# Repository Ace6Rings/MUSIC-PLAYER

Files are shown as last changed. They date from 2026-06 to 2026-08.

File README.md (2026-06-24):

# NOIR MUSIC PLAYER
Noir Music Player (3)

# Why?

Why did I build something like this? Well, I am sick and tired of buying spotify premium every month. I looked for mp3 players online but nearly all of them have the same flaw(s). 
They either have a very short battery life or they don't support bluetooth. This would mean that my headphones will last three times as long as a typical mp3 player. So, I solved all of these problems with my own music player.

# Features

  - expandable storage via micro sd card
  - bluetooth range of ~100 meters in open air
  - Dual compatibility with both wired and wireless. 
  - High quality wired and wireless audio
  - Extremely high battery life (not tested)

## Electronics

So what about my electronics makes these features possible?

I use the NRF5430 <br>
  - The NRF5430 is a dual core chip that have the capability of being hyper efficient during its operation. <br>
  - Its power consumption is measured in the microamps during sleep mode and miliamps during full operation.

The PCM5102A and the TPA6132A2RTE <br>
  - the audio from common microcontrollers are low quality and unenjoyable for music. So I used the PCM5102A. It is a high quality DAC which will be wired to the TPA6132ARTE. <br>
  - the TPA6132ARTE increases the volume of the sound and also helps with the bass.<br>
  - with these two components, the wired quality should be no different (if not, better) than a phone or a typical mp3 player.

What about some safety features?

I have 2 layers of protection.

  According to my schematic, the battery and the usbc is tied to the same net. This means that they share the same electrical path.<br>
  To prevent any damage, I used mosfets which prevents both of them from turning on at the same time.<br>
  Additionally, I used the PRTR5V0U2X. It is a tvs diode which can prevent damage to the usbc and the board if something goes horribly wrong.

The rest of the electronics can be found in the electronics subdirectory. You can also find the production files there too. For the reviewer, make sure to read the mini readme in the electronics directory.
step 1 (2)

## Mechanical

The case of the music player is largely modeled after the Iphone 16 pro's dimensions. It is a reasonable size for a mp3 player and is also the reason why I can fit such a big battery.

There isn't any special about the case itself. This is designed for printers like the A1 mini, A1, and X1 Carbon with PLA basic.
If you took a look at my CAD already, you might be worried about how thin the wall is at the micro sd slot. So I ran some simulations.

I put a force of 20 newtons onto the faces of the socket and made the opposite wall a fixed support.
There could be more things you might want to see. You can do that under MECHANICAL and then click on simulations. <br>
NOTE: you need both the workbench file and also the zipped file too
CONTROL
control
This is the "before" part of the simulation.
defform
And this is the after. 

Pretty much the same right? this means that my design is sound and could be used (as long as the user isn't a brute)

## Code
### MAKE SURE TO READ THE CORRESPONDING README INCLUDED IN THE CODE DIRECTORY TO ACTUALLY BUILD IT.
The backend of the code is built entirely by NORDIC, the company behind the NRF chips. I used their existing audio code so that I don't need to code my own (they have tens of thousands of lines of code)

The gui and function is limited because I have not recieved my pcb yet, and won't know what will happen if i implement something more than audio playback and some config files. This will change once I get my pcb.

Also note that the vast majority of the code is by NORDIC and their open source templates. All I did was make config files.

# Process

So what exactly is under the hood? Its a big schematic, so there is going to be 3 images.

## Schematic


As you can see, I'm using the NRF 5340 to power this project. Is there really much to say about this as of right now? Not really.



In this image, we can see that I'm using the TPA and PCM. These components work together to make wired audio great (hopefully). On the user side, you don't have to worry about this.
There is a headphone jack, and that is where you're going to plug in your headphones.



(yeah i don't know what to say about the schematic, I guess its cool?)

## PCB

If you've already opened the PCB file, then you might've been confused or bamboozled by how messy it is. But it really isn't!

This is what it is supposed to look like without user drawings (i used them to align things but never deleted them so I remember how much pain I went through).

Everything that needed to be said is already said in the features subtitle, but as an addendum, I added a cool snowman.



# How to use
Well how do you use it? I don't really know to be honest. The code is rudimentary and will be improved upon when I get my parts. As of right now, the controls are simple. The four buttons indicate direction, the center button indicates selection, and the rotary encoder is for volume up down and also a faster way to navigate the (future) gui.

# How to build

If you want to know how to build this physically, then heres a simple guide.

Thankfully, you don't need to do much at all! (assuming your pcb is already assembled. If not, good luck)

INSTRUCTION DIAGRAM (1)-1

Just follow the steps in order!

1.Grab a soldering iron to put heat set inserts into the hole that label 1 is indicating. This is OPTIONAL, but you will need to adjust the cad to make it 2mm instead of 3mm.<br>
2.Screw in the screws as indicated in Label 1. There is only two holes but four mounts. Make sure to orientate it correctly! (the ports should line up with the case)<br>
3.Put the battery inside the two walls as indicated in label 2. Since everyone's printers are different, you will likely have to sand it. You can put double sided tape or velcro to secure the battery further, but otherwise, it should be fine. <br>
4.Put the ANO encoder into the cutout as indicated in Label 4.<br>
5.Put the cover onto the ANO encoder as indicated in Label 5.<br>
6.Screw it both in as indicated in Label 6.<br>
6.Use the JST compatible wires and connect them to the PCB.<br>
7.Do the same thing you just did to the ANO encoder in step 3. Instead, this time, you'll apply the same principle to the screen in Label 7, 8, and 9.<br>
NOTE: If you are unconfident in your soldering abilities, especially for the screen, you may adjust the "leeway" variable under "screen" folder and then the "mount" subfolder. The default is 2mm, do not go past 2.1mm. You may lower it if you want to, but the default should be ok. In addition, it is not reccomended to use the included pin headers for the screen, just solder the wire directly. The cover will hide any cosmetic issues.<br>

Hey! What about the battery? <br>
Well, since everyone can choose what lipo battery they will be using, I decided to make the battery area an open space. All you have to do is take a small piece of double sided tape (which many other commericial products do!) and tape the battery to the case. 

# BOM

NOTE: This file might be confusing. So heres some clarifications <br>

  - QTY refers to the actual amount needed. Amount refers to the amount bought due to minimum purchase limits. For assortment kits, qty is just 1.
  - Any item below the 45th row is not needed for this project (well they are). They are misc items that I don't have and I must put it down to get funding.
  - The NRF 5340 DK dev board is not needed, you only need a pico or etc to serve as an external programmer. I need this because I need to debug my code after I recieve my parts (so yes, again, this is for funding purposes)
  - shipping is done weirdly because I don't know how else to do it. However, you don't have to worry about that. There is a number on a seemingly random item that tells you the shipping price. Since alot of these items come from the same shop, the shipping is counted once. So items only have a shipping fee if it is the first on the list (by row) to have that specific shop.

And additionally, you might be thinking "woah, why is this so expensive?!" <br>
Well, most of the cost is actually the tools I need to program and assemble my project. You might already have these items!<br>

[tableConvert.com_6tsmnr.md](https://github.com/user-attachments/files/29273329/tableConvert.com_6tsmnr.md)
| Reference | Qty | Item | DNP | Exclude from BOM | Exclude from Board  | Footprint | Datasheet | Link | Amount | Cost  | SUBTOTAL | SHIPPING | TAXES | TOTAL |
|---|-----|---|-----|---|---|---|---|---|---|---|---|---|---|---|
| C1,C4,C8,C10,C12,C24,C39,C40,C41,C43,C44,C45,C46,C50,C53 | 15  | 1u | | | | Capacitor_SMD:C_0402_1005Metric | | https://www.lcsc.com/product-detail/C29266.html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 | 100 | 0.53  | 209.2 | 7.27 | 21.724225 | 266.504225 |
| C2, C26, C47 | 3 | 2.2u | | | | Capacitor_SMD:C_0402_1005Metric | | https://www.lcsc.com/product-detail/C170151.html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 | 50 | 0.5 | | | | |
| C3,C7,C15,C16,C17,C18,C19,C20,C21,C22,C23,C28,C29,C30,C31,C32,C33,C36,C38,C42,C48,C51,C52 | 23  | 100n | | | | Capacitor_SMD:C_0402_1005Metric | | https://www.lcsc.com/product-detail/C1525.html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 | 100 | 0.23  | | | | |
| C5 | 1 | 4.7u | DNP | | Excluded from board | Capacitor_SMD:C_0603_1608Metric | | | | | | | | |
| C6,C9,C11,C27 | 4 | 4.7u | | | | Capacitor_SMD:C_0603_1608Metric | | https://www.lcsc.com/product-detail/C19666.html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 | 10 | 0.22  | | | | |
| C13 | 1 | 2.2n | | | | Capacitor_SMD:C_0402_1005Metric | | https://www.lcsc.com/product-detail/C107082.html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 | 100 | 0.42  | | | | |
| C14 | 1 | 0.7p | | | | Capacitor_SMD:C_0402_1005Metric | | https://www.lcsc.com/product-detail/C161349.html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 | 50 | 0.83  | | | | |
| C37,C49 | 2 | 10u | | | | Capacitor_SMD:C_0603_1608Metric | | https://www.lcsc.com/product-detail/C96446.html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 | 20 | 1.07  | | | | |
| C54 | 1 | 10n | | | | Capacitor_SMD:C_0402_1005Metric | | https://www.lcsc.com/product-detail/C15195.html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 | 100 | 0.25  | | | | |
| C55 | 1 | NC | DNP | | | Capacitor_SMD:C_0402_1005Metric | | | | | | | | |
| D1, D3 | 2 | POWER | | | | LED_SMD:LED_0603_1608Metric | | https://www.lcsc.com/product-detail/C19171394.html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 | 100 | 0.58  | | | | |
| D2 | 1 | PRTR5V0U2X | | | | Package_TO_SOT_SMD:SOT-143 | https://assets.nexperia.com/documents/data-sheet/PRTR5V0U2X.pdf | https://www.lcsc.com/product-detail/C2827688.html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 | 10 | 0.61  | | | | |
| E1 | 1 | 2450AT43B100E | | | | MyFootprintLibrary:ANTENNA_2450AT43B100E | | https://www.lcsc.com/product-detail/C2917721.html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 | 1 | 0.77  | | | | |
| FB1,FB2 | 2 | TDK MPZ1608S221ATA00 | | | | myotherkicadfootprintlibrary:IND_1608_TDK | | https://www.lcsc.com/product-detail/C76815.html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 | 10 | 0.15  | | | | |
| J1 | 1 | USB_C_Receptacle_USB2.0_16P | | | | Connector_USB:USB_C_Receptacle_GCT_USB4105-xx-A_16P_TopMnt_Horizontal | https://www.usb.org/sites/default/files/documents/usb_type-c.zip | https://www.lcsc.com/product-image/C5184243.html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 | 1 | 0.97  | | | | |
| J2 | 1 | JST CONNECTOR 1X3 | | | | Connector_JST:JST_PH_S3B-PH-K_1x03_P2.00mm_Horizontal | | https://www.lcsc.com/product-detail/C157929.html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 | 10 | 0.49  | | | | |
| J3 | 1 | JST CONNECTOR 1X2 | | | | Connector_JST:JST_PH_S2B-PH-K_1x02_P2.00mm_Horizontal | | https://www.lcsc.com/product-detail/C173752.html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 | 20 | 0.79  | | | | |
| J4 | 1 | MSD-4-A | | | | MyFootprintLibrary:CUI_MSD-4-A | | https://www.lcsc.com/product-detail/C22367949.html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 | 1 | 0.83  | | | | |
| J5 | 1 | SJ-43514 | | | | MyFootprintLibrary:CUI_SJ-43514 | | https://www.digikey.com/en/products/detail/same-sky-formerly-cui-devices/SJ-43514/368146 | 1 | 1.34  | | | | |
| L1, L2, L3 | 3 | 10uH | | | | Inductor_SMD:L_0402_1005Metric | | https://www.lcsc.com/product-detail/C910650.html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 | 5 | 3.01  | | | | |
| L4 | 1 | 2.2n | | | | Inductor_SMD:L_0402_1005Metric | | https://www.lcsc.com/product-detail/C91240.html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 | 10 | 0.5 | | | | |
| Q1,Q2 | 2 | DMG2301L | | | | Package_TO_SOT_SMD:SOT-23 | https://www.diodes.com/assets/Datasheets/DMG2301L.pdf | https://www.lcsc.com/product-detail/C7472914.html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 | 10 | 0.58  | | | | |
| R1,R2 | 2 | 5.1K | | | | Resistor_SMD:R_0402_1005Metric | | https://www.lcsc.com/product-detail/C852856.html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 | 50 | 1.08  | | | | |
| R3, R13, R14 | 3 | 10k | | | | Resistor_SMD:R_0402_1005Metric | | https://www.lcsc.com/product-detail/C190095.html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 | 50 | 0.93  | | | | |
| R4 | 1 | 2R2 | | | | Resistor_SMD:R_0402_1005Metric | | https://www.lcsc.com/product-detail/C3013277.html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 | 50 | 0.64  | | | | |
| R5 | 1 | 100 | | | | Resistor_SMD:R_0402_1005Metric | | https://www.lcsc.com/product-detail/C106232.html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 | 100 | 0.1 | | | | |
| R6 | 1 | 1k | | | | Resistor_SMD:R_0402_1005Metric | | https://www.lcsc.com/product-detail/C852624.html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 | 50 | 0.89  | | | | |
| R7 | 1 | 2.2k | | | | Resistor_SMD:R_0402_1005Metric | | https://www.lcsc.com/product-detail/C2906920.html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 | 100 | 0.1 | | | | |
| R8,R9 | 2 | 1M | | | | Resistor_SMD:R_0402_1005Metric | | https://www.lcsc.com/product-detail/C2929915.html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 | 100 | 0.1 | | | | |
| R10 | 1 | 2k | | | | Resistor_SMD:R_0402_1005Metric | | https://www.lcsc.com/product-detail/C2906921.html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 | 100 | 0.09  | | | | |
| R11 | 1 | 22k | | | | Resistor_SMD:R_0402_1005Metric | | https://www.lcsc.com/product-detail/C82868.html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 | 100 | 0.1 | | | | |
| R12 | 1 | 470 | | | | Resistor_SMD:R_0402_1005Metric | | https://www.lcsc.com/product-detail/C2909361.html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 | 100 | 0.1 | | | | |
| R15 | 1 | 4.7k | | | | Resistor_SMD:R_0402_1005Metric | | https://www.lcsc.com/product-detail/C42396697.html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 | 100 | 0.22  | | | | |
| SW1 | 1 | B3U-1000P | | | | myotherkicadfootprintlibrary:B3U-1000P | | https://www.lcsc.com/product-detail/C231329.html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 | 5 | 0.89  | | | | |
| U1 | 1 | | | | | Connector_JST:JST_PH_S9B-PH-K_1x09_P2.00mm_Horizontal | | https://www.lcsc.com/product-detail/C157912.html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 | 5 | 0.92  | | | | |
| U2 | 1 | nRF5340-QKAA-R | | | | Package_DFN_QFN:Nordic_AQFN-94-1EP_7x7mm_P0.4mm | https://infocenter.nordicsemi.com/pdf/nRF5340_PS_v1.2.pdf | https://www.lcsc.com/product-detail/C3015611.html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 | 1 | 7.59  | | | | |
| U3 | 1 | SPX3819M5-L-3-3 | | | | Package_TO_SOT_SMD:SOT-23-5 | https://www.exar.com/content/document.ashx?id=22106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 | https://www.lcsc.com/product-detail/C9055.html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 | 10 | 1.78  | | | | |
| U4 | 1 | | | | | Connector_JST:JST_PH_S8B-PH-K_1x08_P2.00mm_Horizontal | | https://www.lcsc.com/product-detail/C157915.html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 | 5 | 0.54  | | | | |
| U5 | 1 | MCP73831-2-OT | | | | Package_TO_SOT_SMD:SOT-23-5 | http://ww1.microchip.com/downloads/en/DeviceDoc/20001984g.pdf | https://www.lcsc.com/product-detail/C424093.html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 | 1 | 0.81  | | | | |
| U6 | 1 | TPA6132A2RTE | | | | Package_DFN_QFN:WQFN-16-1EP_3x3mm_P0.5mm_EP1.6x1.6mm_ThermalVias | https://www.ti.com/lit/ds/symlink/tpa6132a2.pdf | https://www.lcsc.com/product-detail/C69901.html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 | 1 | 1.31  | | | | |
| U7 | 1 | PCM5102A | | | | Package_SO:TSSOP-20_4.4x6.5mm_P0.65mm | http://www.ti.com/lit/ds/symlink/pcm5100.pdf | https://www.lcsc.com/product-detail/C107671.html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 | 1 | 1.11  | | | | |
| Y1 | 1 | Seiko SC-20S | | | | Crystal:Crystal_SMD_2012-2Pin_2.0x1.2mm | | https://www.digikey.com/en/products/detail/seiko-instruments/SC20S-7PF20PPM/4931506 | 1 | 0.72  | | 8.49 | | |
| Y2 | 1 | NX2016SA-CS06654 | | | | myotherkicadfootprintlibrary:NX2016SA_NDK | | https://www.lcsc.com/product-detail/C5441424.html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 | 1 | 0.44  | | | | |
| | | NRF 5340 DK | | | | | | " | | | | | | |
| https://www.digikey.com/en/products/detail/nordic-semiconductor-asa/NRF5340-DK/13544603"  | 1 | 48.95 | | | | | | | | | | | | |
| | | Adafruit ANO Rotary Navigation Encoder | | | | | | https://www.adafruit.com/product/6311 | 1 | 10.95 | | 8.62 | | |
| | | 2.0 Inch 240x320 Full Color TFT LCD Display Module with ST7789 Controller, SPI/Parallel Interface for arduino | | | | | | https://www.aliexpress.us/item/3256808604270561.html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 | 1 | 4.51  | | | | |
| | | JST CONNECTORS ASSORTMENT KIT | | | | | | https://www.amazon.com/2-0mm-Connectors-Pre-Crimped-Ribbon-Kit/dp/B0FJ11TPNF/ref=sr_1_5?sr=8-5 | 1 | 15.99 | | | | |
| | | SCREW ASSORTMENT KIT | | | | | | https://www.aliexpress.us/item/3256806672911442.html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 | 1 | 4.21  | | | | |
| | | HEAT SET INSERT ASSORTMENT KIT | | | | | | https://www.aliexpress.com/item/3256809278637626.html | 1 | 6.49  | | | | |
| | | JLC PCB | | | | | | | 1 | 5.57  | | 11.2 | | |
| | | LIPO | | | | | | https://www.adafruit.com/product/2011 | 1 | 12.5  | | | | |
| | | Heat gun | | | | | | https://www.aliexpress.us/item/3256809090445917.html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 | 1 | 33.49 | | | | |
| | | Hot plate | | | | | | https://www.aliexpress.us/item/3256807801230251.html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 | 1 | 31.41 | | | | |

The BOM of the pcb itself is included under the electronics directory. Technically, you can program this using just a raspberry pi pico. But as I said again, I need to make sure the code actually works. <br>

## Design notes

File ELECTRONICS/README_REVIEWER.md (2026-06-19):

SOME NOTES FOR THE REVIEWER 

B12 and B14 are intentionally connected to provide a path for B14 to go out. B12 serves no purpose and is physically disconnected according to the Nordic datasheet at
https://www.mouser.com/datasheet/2/297/nRF5340_OPS_v0_5_1-1929595.pdf 
There is also an official source at https://devzone.nordicsemi.com/f/nordic-q-a/61084/nrf52840-reset-pin-routing-to-avoid-pad-on-via which was replied to by "Simonr,"
a Nordic support engineer.

You will likely run the drc and find errors about the courtyard for the crystal. Its just a cosmetic issue.

Silkscreen labels for important/unique components are included. Since its so dense, I did not include any for passive components.

Some silkscreen for the MSD-4-A, the SJ-43514, and the jst connector are deleted. That is why there is a warning for it not matching the footprint library. It is purely cosmetic and won't have any problems during assembly.

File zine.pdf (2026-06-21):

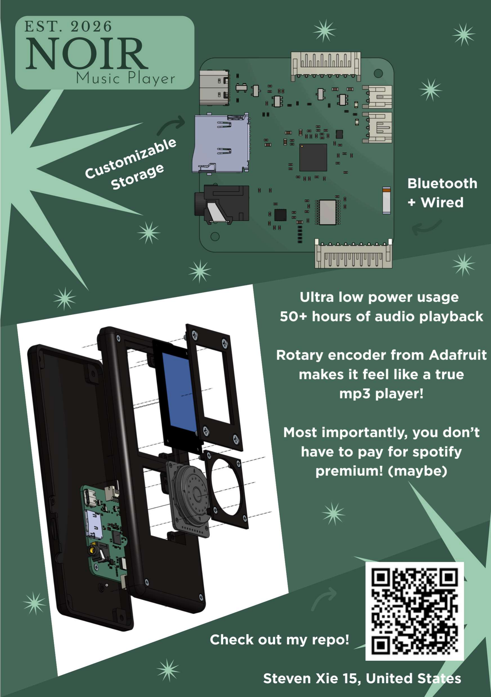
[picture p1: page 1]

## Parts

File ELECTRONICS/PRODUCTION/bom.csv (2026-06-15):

Designator | Footprint | Quantity | Value | LCSC Part #
C1, C10, C12, C24, C39, C4, C40, C41, C43, C44, C45, C46, C50, C53, C8 | 0402 | 15 | 1u
C11, C27, C6, C9 | 0603 | 4 | 4.7u
C13, L4 | 0402 | 2 | 2.2n
C14 | 0402 | 1 | 0.7p
C15, C16, C17, C18, C19, C20, C21, C22, C23, C28, C29, C3, C30, C31, C32, C33, C36, C38, C42, C48, C51, C52, C7 | 0402 | 23 | 100n
C2, C26, C47 | 0402 | 3 | 2.2u
C37, C49 | 0603 | 2 | 10u
C54 | 0402 | 1 | 10n
C55 | 0402 | 1 | NC
D1 | 0603 | 1 | POWER
D2 | SOT-143 | 1 | PRTR5V0U2X
D3 | 0603 | 1 | LED
E1 | ANTENNA_2450AT43B100E | 1 | 2450AT43B100E
FB1, FB2 | IND_1608_TDK | 2 | TDK MPZ1608S221ATA00
J1 | USB_C_Receptacle_GCT_USB4105-xx-A_16P_TopMnt_Horizontal | 1 | USB_C_Receptacle_USB2.0_16P
J2 | JST_PH_S3B-PH-K_1x03_P2.00mm_Horizontal | 1 | Screw_Terminal_01x03
J3 | JST_PH_S2B-PH-K_1x02_P2.00mm_Horizontal | 1 | Screw_Terminal_01x02
J4 | CUI_MSD-4-A | 1 | MSD-4-A
J5 | CUI_SJ-43514 | 1 | SJ-43514
L1 | 0402 | 1 | 10uH
L2, L3 | 0402 | 2 | 10u
Q1, Q2 | SOT-23 | 2 | DMG2301L
R1, R2 | 0402 | 2 | 5.1K
R10 | 0402 | 1 | 2k
R11 | 0402 | 1 | 22k
R12 | 0402 | 1 | 470
R13, R14, R3 | 0402 | 3 | 10K
R15 | 0402 | 1 | 4.7k
R4 | 0402 | 1 | 2R2
R5 | 0402 | 1 | 100
R6 | 0402 | 1 | 1k
R7 | 0402 | 1 | 2.2k
R8, R9 | 0402 | 2 | 1M
SW1 | B3U-1000P | 1 | RESET
U1 | JST_PH_S9B-PH-K_1x09_P2.00mm_Horizontal | 1 | ~
U2 | Nordic_AQFN-94-1EP_7x7mm_P0.4mm | 1 | nRF5340-QKxx
U3 | SOT-23-5 | 1 | SPX3819M5-L-3-3
U4 | JST_PH_S8B-PH-K_1x08_P2.00mm_Horizontal | 1 | ~
U5 | SOT-23-5 | 1 | MCP73831-2-OT
U6 | WQFN-16-1EP_3x3mm_P0.5mm_EP1.6x1.6mm_ThermalVias | 1 | TPA6132A2RTE
U7 | TSSOP-20_4.4x6.5mm_P0.65mm | 1 | PCM5102A
Y1 | Crystal_SMD_2012-2Pin_2.0x1.2mm | 1 | Seiko SC-20S
Y2 | NX2016SA_NDK | 1 | NX2016SA-CS06654

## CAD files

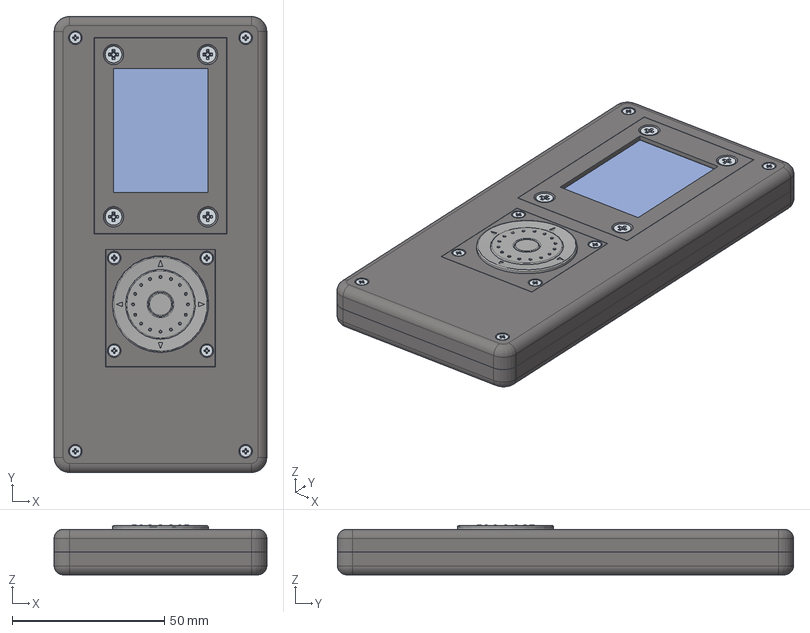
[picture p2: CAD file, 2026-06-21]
MECHANICAL/CAD/FINAL ASSEMBLY.step
70.0 x 150.0 x 16.4 mm
PH Countersunk flat head screw M2x0.4 x 6 x 8
PH Countersunk flat head screw M3x0.5 x 6 x 4
Battery
BottomHalf
TopHalf
Board
PH Countersunk flat head screw M2x0.4 x 3 x 2
Ano
Screen
NRF5340-QKAA-R7--3DModel-STEP-269445 x 101
C_0603_1608Metric x 7
C_0402_1005Metric x 44
R_0402_1005Metric x 15
Same_Sky_SJ-43514 x 3
USB_C_Receptacle_GCT_USB4105-xx-A_16P_TopMnt_Horizontal x 36
WQFN-16-1EP_3x3mm_P0.5mm_EP1.6x1.6mm
NX2016SA_NDK x 6
TSSOP-20_4.4x6.5mm_P0.65mm
L_0402_1005Metric x 4
2450AT43B100E--3DModel-STEP-56544 x 6
SOT-143
JST_PH_S2B-PH-K_1x02_P2.00mm_Horizontal
Music-player_PCB
JST_PH_S9B-PH-K_1x09_P2.00mm_Horizontal
SOT-23-5 x 2
LED_0603_1608Metric x 2
JST_PH_S3B-PH-K_1x03_P2.00mm_Horizontal
MSD-4-A
SOT-23 x 2
JST_PH_S8B-PH-K_1x08_P2.00mm_Horizontal

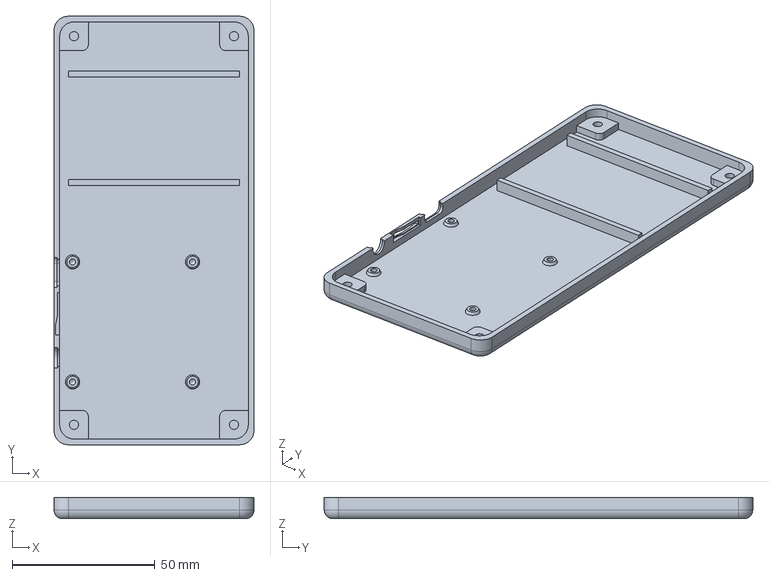
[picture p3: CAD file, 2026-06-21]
MECHANICAL/CAD/CASE - BottomHalf.step
70.0 x 150.0 x 7.50 mm

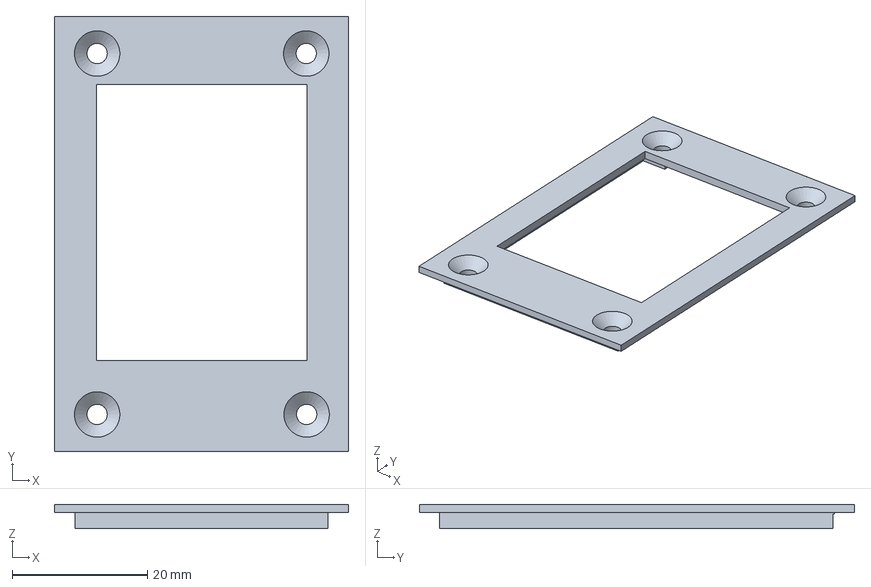
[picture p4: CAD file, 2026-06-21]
MECHANICAL/CAD/CASE - Screen.step
43.5 x 64.4 x 3.60 mm

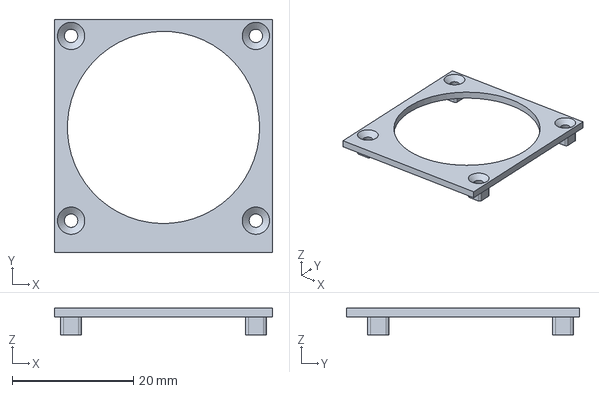
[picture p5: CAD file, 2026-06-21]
MECHANICAL/CAD/CASE - Ano.step
36.0 x 38.5 x 4.43 mm

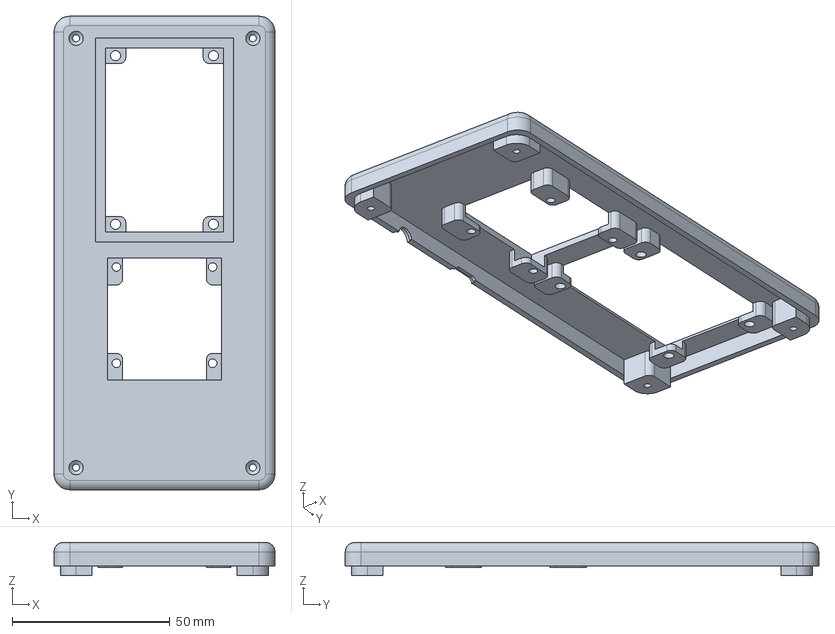
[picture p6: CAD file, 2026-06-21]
MECHANICAL/CAD/CASE - TopHalf.step
70.0 x 150.0 x 10.5 mm

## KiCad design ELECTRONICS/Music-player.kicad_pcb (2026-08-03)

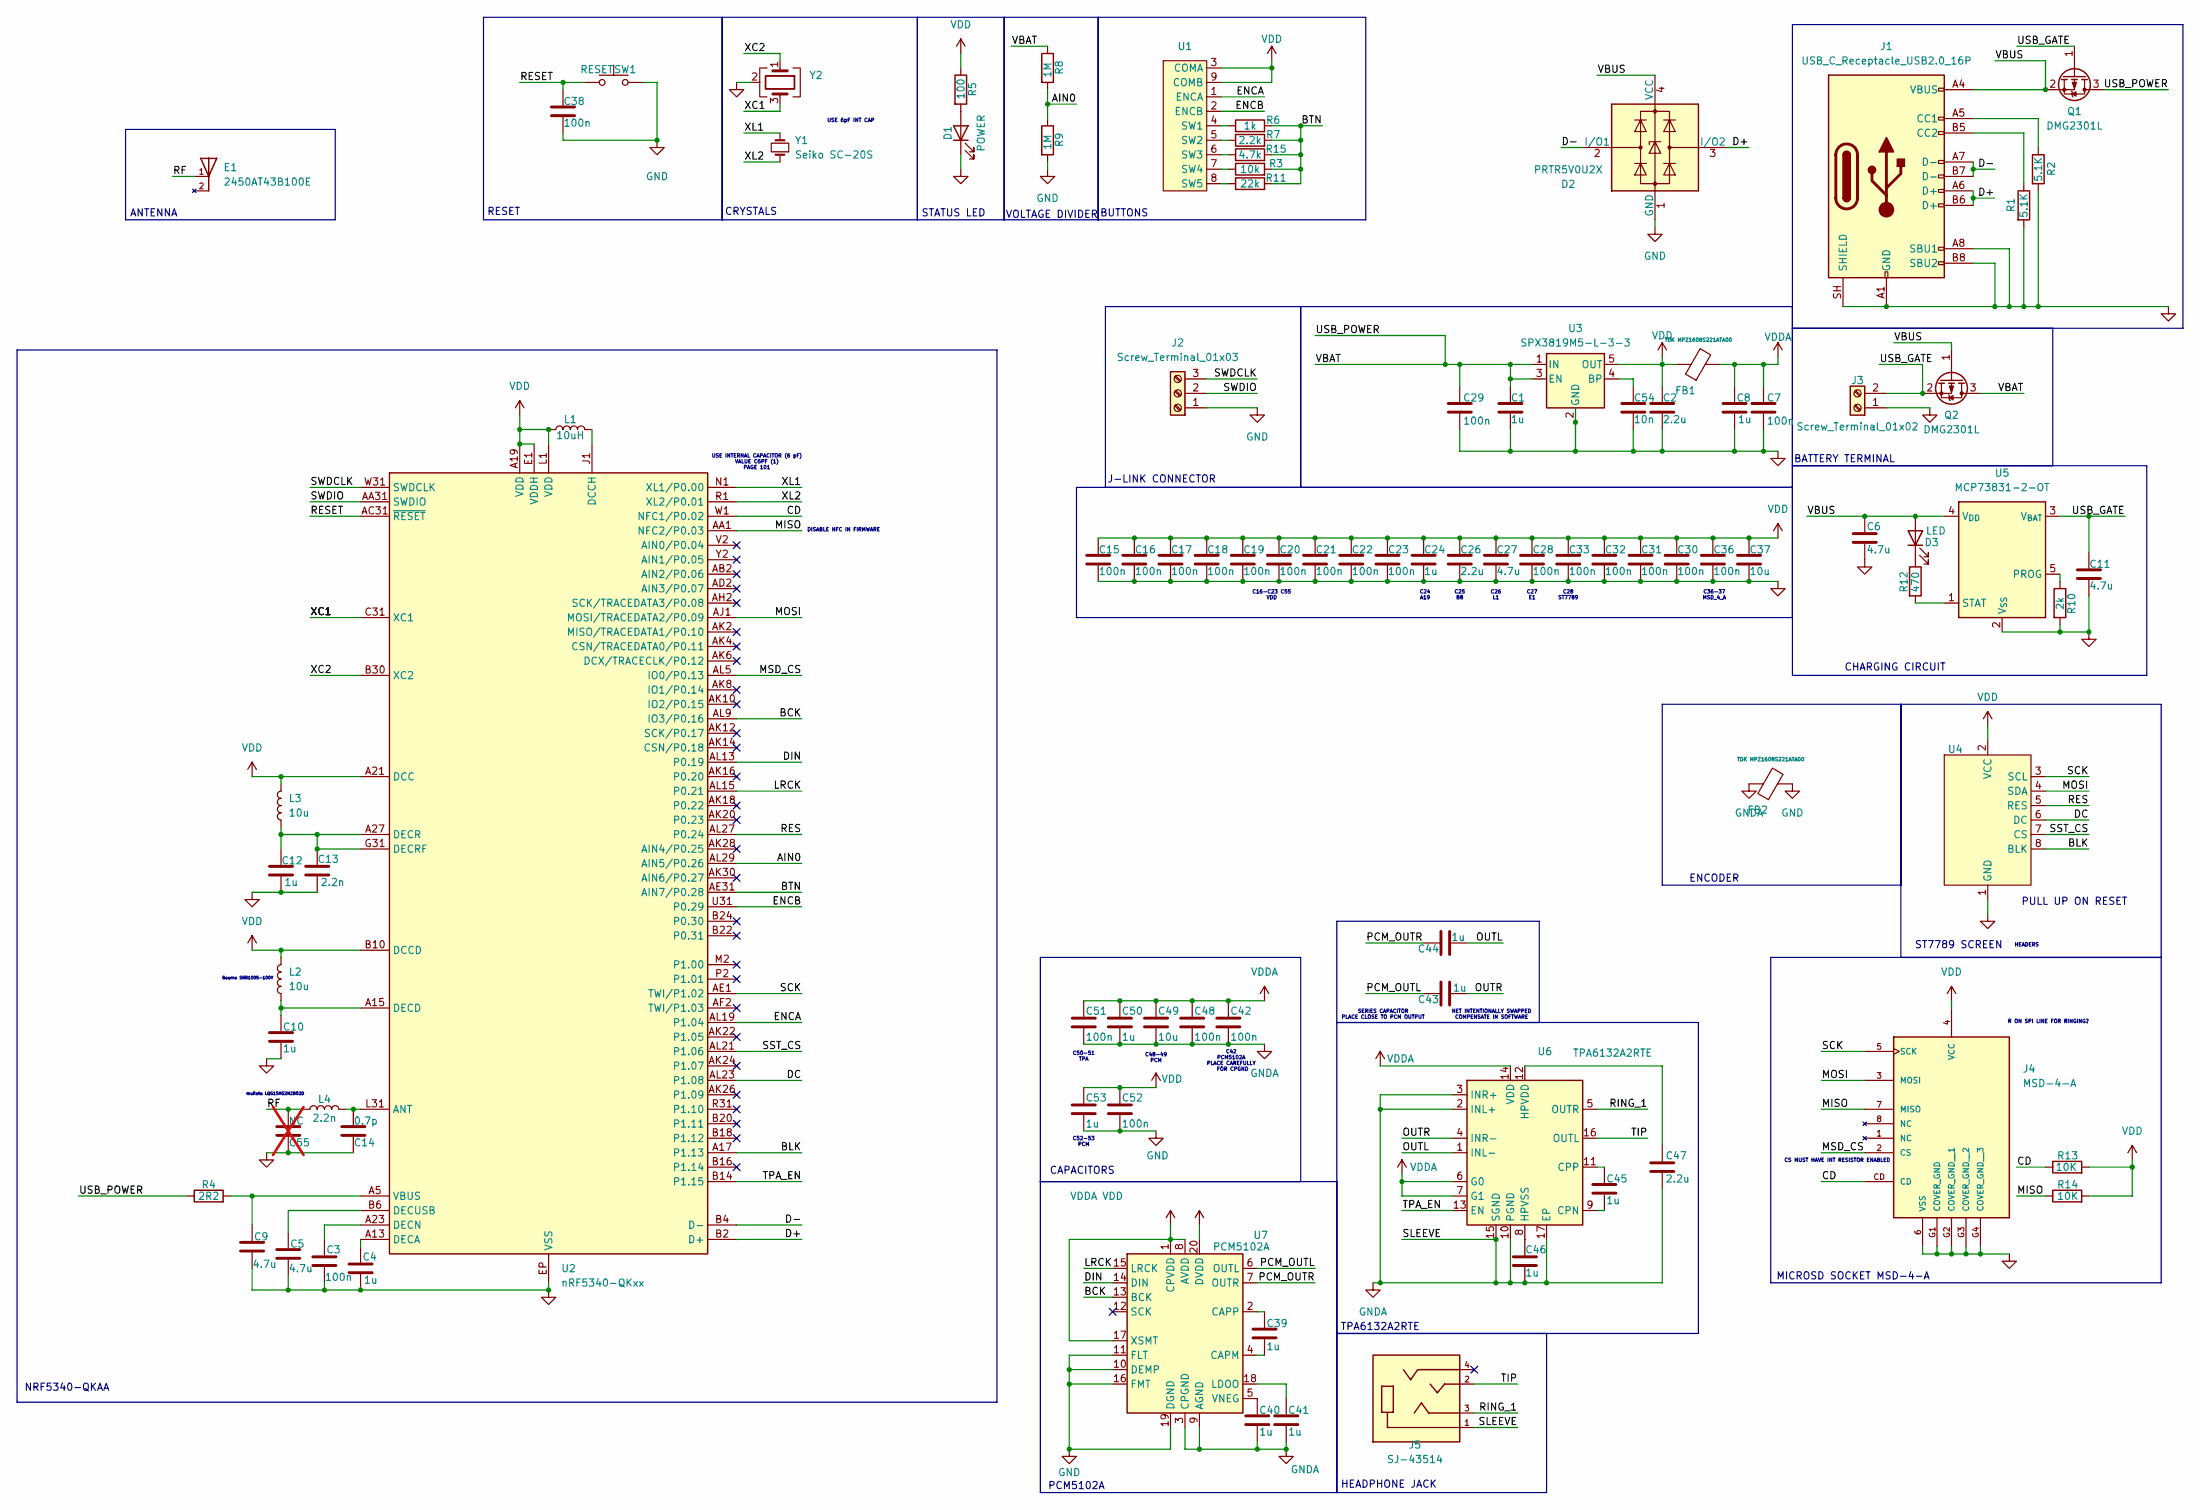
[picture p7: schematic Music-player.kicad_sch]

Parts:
C1, C4, C8, C10, C12, C24, C39, C40, C41, C43, C44, C45, C46, C50, C53: 1u; C_0402_1005Metric
C2, C26, C47: 2.2u; C_0402_1005Metric
C3, C7, C15, C16, C17, C18, C19, C20, C21, C22, C23, C28, C29, C30, C31, C32, C33, C36, C38, C42, C48, C51, C52: 100n; C_0402_1005Metric
C5, C6, C9, C11, C27: 4.7u; C_0603_1608Metric
C13: 2.2n; C_0402_1005Metric
C14: 0.7p; C_0402_1005Metric
C37, C49: 10u; C_0603_1608Metric
C54: 10n; C_0402_1005Metric
C55: NC; C_0402_1005Metric; not fitted
D1: POWER; LED_0603_1608Metric
D2: PRTR5V0U2X; SOT-143
D3: LED; LED_0603_1608Metric
E1: 2450AT43B100E; ANTENNA_2450AT43B100E; PARTREV 4.0
FB1, FB2: TDK MPZ1608S221ATA00; IND_1608_TDK
J1: USB_C_Receptacle_USB2.0_16P; USB_C_Receptacle_GCT_USB4105-xx-A_16P_TopMnt_Horizontal
J2: Screw_Terminal_01x03; JST_PH_S3B-PH-K_1x03_P2.00mm_Horizontal
J3: Screw_Terminal_01x02; JST_PH_S2B-PH-K_1x02_P2.00mm_Horizontal
J4: MSD-4-A; CUI_MSD-4-A; PARTREV 1.0
J5: SJ-43514; CUI_SJ-43514; PART_REV 1.04
L1: 10uH; L_0402_1005Metric
L2, L3: 10u; L_0402_1005Metric
L4: 2.2n; L_0402_1005Metric
Q1, Q2: DMG2301L; SOT-23
R1, R2: 5.1K; R_0402_1005Metric
R3: 10k; R_0402_1005Metric
R4: 2R2; R_0402_1005Metric
R5: 100; R_0402_1005Metric
R6: 1k; R_0402_1005Metric
R7: 2.2k; R_0402_1005Metric
R8, R9: 1M; R_0402_1005Metric
R10: 2k; R_0402_1005Metric
R11: 22k; R_0402_1005Metric
R12: 470; R_0402_1005Metric
R13, R14: 10K; R_0402_1005Metric
R15: 4.7k; R_0402_1005Metric
SW1: RESET; B3U-1000P
U1: JST_PH_S9B-PH-K_1x09_P2.00mm_Horizontal
U2: nRF5340-QKxx; Nordic_AQFN-94-1EP_7x7mm_P0.4mm
U3: SPX3819M5-L-3-3; SOT-23-5
U4: JST_PH_S8B-PH-K_1x08_P2.00mm_Horizontal
U5: MCP73831-2-OT; SOT-23-5
U6: TPA6132A2RTE; WQFN-16-1EP_3x3mm_P0.5mm_EP1.6x1.6mm_ThermalVias
U7: PCM5102A; TSSOP-20_4.4x6.5mm_P0.65mm
Y1: Seiko SC-20S; Crystal_SMD_2012-2Pin_2.0x1.2mm
Y2: NX2016SA-CS06654; NX2016SA_NDK

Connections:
/AIN0: R8.2, R9.1, U2.AL29 (AIN5/P0.26)
/BCK: U2.AL9 (IO3/P0.16), U7.13 (BCK)
/BLK: U2.A17 (P1.13), U4.8 (BLK)
/BTN: R3.2, R6.2, R7.2, R11.2, R15.2, U2.AE31 (AIN7/P0.28)
/CD: J4.CD, R13.1, U2.W1 (NFC1/P0.02)
/D+: D2.3 (I/O2), J1.A6 (D+), J1.B6 (D+), U2.B2 (D+)
/D-: D2.2 (I/O1), J1.A7 (D-), J1.B7 (D-), U2.B4 (D-)
/DC: U2.AL23 (P1.08), U4.6 (DC)
/DIN: U2.AL13 (P0.19), U7.14 (DIN)
/ENCA: U1.1 (ENCA), U2.AL19 (P1.04)
/ENCB: U1.2 (ENCB), U2.U31 (P0.29)
/LRCK: U2.AL15 (P0.21), U7.15 (LRCK)
/MISO: J4.7 (MISO), R14.1, U2.AA1 (NFC2/P0.03)
/MOSI: J4.3 (MOSI), U2.AJ1 (MOSI/TRACEDATA2/P0.09), U4.4 (SDA)
/MSD_CS: J4.2 (CS), U2.AL5 (IO0/P0.13)
/OUTL: C44.2, U6.1 (INL-)
/OUTR: C43.2, U6.4 (INR-)
/PCM_OUTL: C43.1, U7.6 (OUTL)
/PCM_OUTR: C44.1, U7.7 (OUTR)
/RES: U2.AL27 (P0.24), U4.5 (RES)
/RESET: C38.1, SW1.1, U2.AC31 (~RESET)
/RF: C55.1, E1.1, L4.1
/RING_1: J5.3, U6.5 (OUTR)
/SCK: J4.5 (SCK), U2.AE1 (TWI/P1.02), U4.3 (SCL)
/SST_CS: U2.AL21 (P1.06), U4.7 (CS)
/SWDCLK: J2.3, U2.W31 (SWDCLK)
/SWDIO: J2.2, U2.AA31 (SWDIO)
/TIP: J5.2, U6.16 (OUTL)
/TPA_EN: U2.B14 (P1.15), U6.13 (EN)
/USB_GATE: C11.1, J3.2, Q1.1 (G), Q2.2 (S), U5.3 (V_{BAT})
/USB_POWER: C1.1, C29.1, Q1.3 (D), Q2.3 (D), R4.1, R8.1, U3.1 (IN), U3.3 (EN)
/VBUS: C6.1, D2.4 (VCC), D3.2 (A), J1.A4 (VBUS), J1.A9 (VBUS), J1.B4 (VBUS), J1.B9 (VBUS), Q1.2 (S), Q2.1 (G), U5.4 (V_{DD})
/XC1: U2.C31 (XC1), Y2.3
/XC2: U2.B30 (XC2), Y2.1
/XL1: U2.N1 (XL1/P0.00), Y1.2
/XL2: U2.R1 (XL2/P0.01), Y1.1
GND: C1.2, C2.2, C3.2, C4.2, C5.2, C6.2, C7.2, C8.2, C9.2, C10.2, C11.2, C12.2, C13.2, C14.2, C15.2, C16.2, C17.2, C18.2, C19.2, C20.2, C21.2, C22.2, C23.2, C24.2, C26.2, C27.2, C28.2, C29.2, C30.2, C31.2, C32.2, C33.2, C36.2, C37.2, C38.2, C52.2, C53.2, C54.2, C55.2, D1.1 (K), D2.1 (GND), FB2.2, J1.A1 (GND), J1.A8 (SBU1), J1.A12 (GND), J1.B1 (GND), J1.B8 (SBU2), J1.B12 (GND), J1.SH (SHIELD), J2.1, J3.1, J4.6 (VSS), J4.G1 (COVER_GND), J4.G2 (COVER_GND__1), J4.G3 (COVER_GND__2), J4.G4 (COVER_GND__3), R1.2, R2.2, R9.2, R10.2, SW1.2, U2.EP (VSS), U3.2 (GND), U4.1 (GND), U5.2 (V_{SS}), U7.10 (DEMP), U7.11 (FLT), U7.16 (FMT), U7.19 (DGND), Y2.2 (G), Y2.4 (G); also elsewhere on the board
GNDA: C40.2, C41.2, C42.2, C46.2, C47.2, C48.2, C49.2, C50.2, C51.2, FB2.1, J5.1, U6.2 (INL+), U6.3 (INR+), U6.10 (PGND), U6.15 (SGND), U6.17 (EP), U7.3 (CPGND), U7.9 (AGND)
unnamed: D1.2 (A), R5.2
unnamed: D3.1 (K), R12.1
unnamed: J1.A5 (CC1), R2.1
unnamed: J1.B5 (CC2), R1.1
unnamed: R6.1, U1.4 (SW1)
unnamed: R7.1, U1.5 (SW2)
unnamed: R15.1, U1.6 (SW3)
unnamed: R3.1, U1.7 (SW4)
unnamed: R11.1, U1.8 (SW5)
unnamed: C14.1, L4.2, U2.L31 (ANT)
unnamed: L1.2, U2.J1 (DCCH)
unnamed: C4.1, U2.A13 (DECA)
unnamed: C10.1, L2.1, U2.A15 (DECD)
unnamed: C3.1, U2.A23 (DECN)
unnamed: C12.1, C13.1, L3.1, U2.A27 (DECR), U2.G31 (DECRF)
unnamed: C54.1, U3.4 (BP)
unnamed: R10.1, U5.5 (PROG)
unnamed: R12.2, U5.1 (STAT)
unnamed: C45.2, U6.9 (CPN)
unnamed: C45.1, U6.11 (CPP)
unnamed: C47.1, U6.12 (HPVDD)
unnamed: C46.1, U6.8 (HPVSS)
unnamed: C39.2, U7.4 (CAPM)
unnamed: C39.1, U7.2 (CAPP)
unnamed: C41.1, U7.18 (LDOO)
unnamed: C40.1, U7.5 (VNEG)
VDD: C2.1, C15.1, C16.1, C17.1, C18.1, C19.1, C20.1, C21.1, C22.1, C23.1, C24.1, C26.1, C27.1, C28.1, C30.1, C31.1, C32.1, C33.1, C36.1, C37.1, C52.1, C53.1, FB1.1, J4.4 (VCC), L1.1, L2.2, L3.2, R5.1, R13.2, R14.2, U1.3 (COMA), U1.9 (COMB), U2.A19 (VDD), U2.A21 (DCC), U2.AC1 (VDD), U2.AG1 (VDD), U2.AJ31 (VDD), U2.AL3 (VDD), U2.AL7 (VDD), U2.AL11 (VDD), U2.AL17 (VDD), U2.AL25 (VDD), U2.B8 (VDD), U2.B10 (DCCD), U2.B28 (VDD), U2.C1 (VDD), U2.E1 (VDDH), U2.E31 (VDD), U2.L1 (VDD), U2.N31 (VDD), U2.U1 (VDD), U3.5 (OUT), U4.2 (VCC), U7.20 (DVDD)
VDDA: C7.1, C8.1, C42.1, C48.1, C49.1, C50.1, C51.1, FB1.2, U6.6 (G0), U6.7 (G1), U6.14 (VDD), U7.1 (CPVDD), U7.8 (AVDD), U7.17 (XSMT)

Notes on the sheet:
C26 L1
SERIES CAPACITOR PLACE CLOSE TO PCM OUTPUT
CS MUST HAVE INT RESISTOR ENABLED
C50-51 TPA
C36-37 MSD_4_A
C28 ST7789
ST7789 SCREEN
VOLTAGE DIVIDER
C24 A19
PULL UP ON RESET
CRYSTALS
CHARGING CIRCUIT
CAPACITORS
MICROSD SOCKET MSD-4-A
STATUS LED
NRF5340-QKAA
USE 6pF INT CAP
C52-53 PCM
C48-49 PCM
RESET
R ON SPI LINE FOR RINGING?
C42 PCM5102A PLACE CAREFULLY FOR CPGND
USE INTERNAL CAPACITOR (6 pF) VALUE C6PF (1) PAGE 101
C16-C23 C55 VDD
C25 B8
TPA6132A2RTE
NET INTENTIONALLY SWAPPED COMPENSATE IN SOFTWARE
ANTENNA
C27 E1
BATTERY TERMINAL
muRata LQG15HS2N2B02D
PCM5102A
DISABLE NFC IN FIRMWARE
BUTTONS
ENCODER
Bourns SRR1005-100Y
J-LINK CONNECTOR
HEADERS
HEADPHONE JACK

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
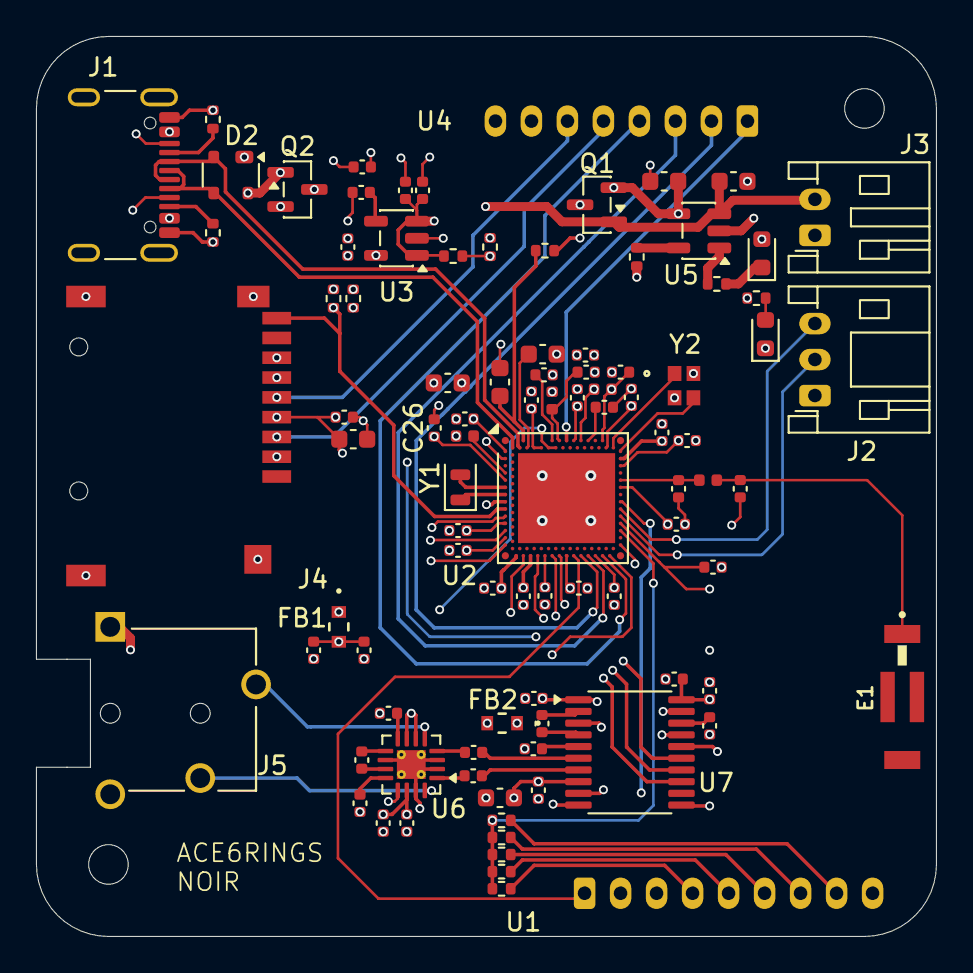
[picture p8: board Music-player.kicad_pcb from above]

Board: 6 copper layers, 50.0 x 50.0 mm, 94 parts (1 on the bottom side), 68 nets.

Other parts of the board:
C9#2: 4.7u; C_0603_1608Metric

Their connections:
GND: C9#2.2; also elsewhere on the board

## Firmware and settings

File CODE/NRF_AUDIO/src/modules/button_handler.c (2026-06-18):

/*
 * Copyright (c) 2018 Nordic Semiconductor ASA
 *
 * SPDX-License-Identifier: LicenseRef-Nordic-5-Clause
 */

#include "button_handler.h"

#include <zephyr/kernel.h>
#include <zephyr/drivers/adc.h>
#include <zephyr/sys/util.h>
#include <zephyr/shell/shell.h>
#include <zephyr/zbus/zbus.h>
#include <zephyr/toolchain/common.h>
#include <stdlib.h>
#include <stdio.h>
#include <ctype.h>

#include "button_assignments.h"
#include "macros_common.h"
#include "zbus_common.h"

#include <zephyr/logging/log.h>
LOG_MODULE_REGISTER(button_handler, CONFIG_MODULE_BUTTON_HANDLER_LOG_LEVEL);

/* Define ZBUS Channel safely now that headers are loaded sequentially */
ZBUS_CHAN_DEFINE(button_chan, struct button_msg, NULL, NULL, ZBUS_OBSERVERS_EMPTY,
        ZBUS_MSG_INIT(0));
#define BASE_10 10

/* Only allow one button msg at a time, as a mean of debounce */
K_MSGQ_DEFINE(button_q, sizeof(struct button_msg), 1, sizeof(void *));

static bool debounce_is_ongoing;

/* Direct device pointer lookup to your ADC hardware peripheral */
static const struct device *adc_dev = DEVICE_DT_GET(DT_NODELABEL(adc));

/* * FIX: Manual configuration block. This bypasses the broken macro engine entirely
 * while mapping precisely to internal hardware SAADC Channel 7 / AIN7 (P0.28).
 */
static const struct adc_channel_cfg m_1st_channel_cfg = {
    .gain             = ADC_GAIN_1_4,
    .reference        = ADC_REF_INTERNAL,
    .acquisition_time = ADC_ACQ_TIME_DEFAULT,
    .channel_id       = 7,
    .input_positive   = 8, /* SAADC_INPUT_AIN7 = P0.28 */
};

/* Map our ADC readings back into virtual ID values for the system shell */
struct analog_btn_map {
    const char *name;
    uint16_t target_voltage;
    uint32_t virtual_pin;
};

/* FIX: virtual_pin uses button assignment macro values so zbus subscribers
 * can identify buttons by the same constants defined in button_assignments.h */
static struct analog_btn_map btn_config_data[] = {
    {"BUTTON_VOLUME_DOWN", 820,  BUTTON_VOLUME_DOWN},
    {"BUTTON_VOLUME_UP",   1640, BUTTON_VOLUME_UP},
    {"BUTTON_PLAY_PAUSE",  2457, BUTTON_PLAY_PAUSE},
    {"BUTTON_4",           3277, BUTTON_4},
    {"BUTTON_5",           4000, BUTTON_5}
};

#define NUM_BUTTONS ARRAY_SIZE(btn_config_data)

static void on_button_debounce_timeout(struct k_timer *timer)
{
    debounce_is_ongoing = false;
}
K_TIMER_DEFINE(button_debounce_timer, on_button_debounce_timeout, NULL);

/* Process matches and push to the application's Zbus message queue */
static void process_analog_press(uint32_t virtual_pin, const char *name)
{
    if (debounce_is_ongoing) {
        return;
    }

    struct button_msg msg;
    int ret;

    LOG_DBG("Pushed analog button name: %s", name);

    msg.button_pin = virtual_pin;
    msg.button_action = BUTTON_PRESS;

    ret = k_msgq_put(&button_q, (void *)&msg, K_NO_WAIT);
    if (ret == -EAGAIN) {
        LOG_WRN("Btn msg queue full");
    }

    debounce_is_ongoing = true;
    k_timer_start(&button_debounce_timer, K_MSEC(CONFIG_BUTTON_DEBOUNCE_MS), K_NO_WAIT);
}

/* Worker thread that continuously reads our ADC hardware ladder */
static void analog_button_scan_thread(void)
{
    int16_t sample_buffer[1];
    struct adc_sequence sequence = {
        .channels    = BIT(7),
        .buffer      = sample_buffer,
        .buffer_size = sizeof(sample_buffer),
        .resolution  = 12,
    };

    while (1) {
        int err = adc_read(adc_dev, &sequence);
        if (err == 0) {
            int32_t reading = sample_buffer[0];

            /* Ignore resting voltage window so floating states don't loop active button events */
            if (reading < 200) { 
                k_msleep(50);
                continue;
            }

            for (size_t i = 0; i < NUM_BUTTONS; i++) {
                if (reading >= (btn_config_data[i].target_voltage - ADC_TOLERANCE) &&
                    reading <= (btn_config_data[i].target_voltage + ADC_TOLERANCE)) {
                    
                    process_analog_press(btn_config_data[i].virtual_pin, btn_config_data[i].name);
                    break;
                }
            }
        }
        k_msleep(50); // Scan window sleep
    }
}
K_THREAD_DEFINE(analog_scan_tid, 1024, analog_button_scan_thread, NULL, NULL, NULL, 5, 0, 0);

static void button_publish_thread(void)
{
    int ret;
    struct button_msg msg;

    while (1) {
        k_msgq_get(&button_q, &msg, K_FOREVER);

        ret = zbus_chan_pub(&button_chan, &msg, K_NO_WAIT);
        if (ret) {
            LOG_ERR("Failed to publish button msg, ret: %d", ret);
        }
    }
}
K_THREAD_DEFINE(Msg_pub_btn, CONFIG_BUTTON_PUBLISH_STACK_SIZE, button_publish_thread, NULL, NULL,
        NULL, K_PRIO_PREEMPT(CONFIG_BUTTON_PUBLISH_THREAD_PRIO), 0, 0);

/* Stubs kept to prevent breaking dependencies in other files */
int button_pressed(uint32_t button_pin, bool *is_pressed)
{
    ARG_UNUSED(button_pin);
    if (is_pressed) {
        *is_pressed = false;
    }
    return 0;
}

int button_handler_init(void)
{
    int ret;

    if (!device_is_ready(adc_dev)) {
        LOG_ERR("ADC device not ready for button handling");
        return -ENODEV;
    }

    ret = adc_channel_setup(adc_dev, &m_1st_channel_cfg);
    if (ret < 0) {
        LOG_ERR("ADC channel setup failed (%d)", ret);
        return ret;
    }

    LOG_INF("Analog Button Handler initialized successfully.");
    return 0;
}

/* Shell functions updated to read our static map data */
static int cmd_print_all_btns(const struct shell *shell, size_t argc, char **argv)
{
    ARG_UNUSED(argc);
    ARG_UNUSED(argv);

    for (uint8_t i = 0; i < NUM_BUTTONS; i++) {
        shell_print(shell, "Id %d: Target ADC: %d -> %s", i, btn_config_data[i].target_voltage,
                btn_config_data[i].name);
    }

    return 0;
}

static int cmd_push_btn(const struct shell *shell, size_t argc, char **argv)
{
    int ret;
    uint8_t btn_idx;
    struct button_msg msg;

    if (argc != 2) {
        shell_error(shell, "Wrong number of arguments provided");
        return -EINVAL;
    }

    if (!isdigit((int)argv[1][0])) {
        shell_error(shell, "Supplied argument is not numeric");
        return -EINVAL;
    }

    btn_idx = strtoul(argv[1], NULL, BASE_10);

    if (btn_idx >= NUM_BUTTONS) {
        shell_error(shell, "Selected button ID out of range");
        return -EINVAL;
    }

    msg.button_pin = btn_config_data[btn_idx].virtual_pin;
    msg.button_action = BUTTON_PRESS;

    ret = zbus_chan_pub(&button_chan, &msg, K_NO_WAIT);
    if (ret) {
        LOG_ERR("Failed to publish button msg, ret: %d", ret);
    }

    shell_print(shell, "Simulated pushing button idx: %d : %s", btn_idx, btn_config_data[btn_idx].name);

    return 0;
}
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

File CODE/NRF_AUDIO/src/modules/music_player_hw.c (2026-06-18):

/*
 * Copyright (c) 2026 Nordic Semiconductor ASA
 *
 * SPDX-License-Identifier: LicenseRef-Nordic-5-Clause
 */

#include "music_player_hw.h"
#include "headphone_amp.h"
#include "battery_monitor.h"
#include "music_ui.h"

#include <zephyr/device.h>
#include <zephyr/devicetree.h>
#include <zephyr/drivers/display.h>
#include <zephyr/drivers/gpio.h>
#include <zephyr/logging/log.h>

LOG_MODULE_REGISTER(music_player_hw, CONFIG_MODULE_MUSIC_PLAYER_HW_LOG_LEVEL);

/* Display device from zephyr,display chosen node */
#ifdef CONFIG_BOARD_MUSIC_PLAYER_NRF5340_CPUAPP
static const struct device *display_dev = DEVICE_DT_GET(DT_CHOSEN(zephyr_display));
#else
static const struct device *display_dev = NULL;
#endif

/* Backlight GPIO from the device tree (gpio-leds binding) */
#ifdef CONFIG_BOARD_MUSIC_PLAYER_NRF5340_CPUAPP
static const struct gpio_dt_spec backlight_gpio = GPIO_DT_SPEC_GET(DT_NODELABEL(backlight), gpios);
#else
static struct gpio_dt_spec backlight_gpio = {0};
#endif

int music_player_hw_init(void)
{
	int ret;

	/* 1. Initialize display and enable backlight (only if available) */
	if (display_dev != NULL) {
		LOG_INF("Display device found, turning on backlight");

		if (backlight_gpio.port != NULL && gpio_is_ready_dt(&backlight_gpio)) {
			ret = gpio_pin_configure_dt(&backlight_gpio, GPIO_OUTPUT_ACTIVE);
			if (ret) {
				LOG_WRN("Failed to configure backlight: %d", ret);
			} else {
				LOG_DBG("Backlight enabled (P1.13)");
			}
		}

		/* Turn off display blanking */
		if (display_dev && device_is_ready(display_dev)) {
			ret = display_blanking_off(display_dev);
			if (ret) {
				LOG_WRN("display_blanking_off failed: %d", ret);
			} else {
				LOG_DBG("Display blanking disabled");
			}
		}
	} else {
		LOG_DBG("No display device configured; skipping backlight init");
	}

	/* 2. Initialize headphone amplifier */
	ret = headphone_amp_init();
	if (ret) {
		LOG_ERR("Failed to initialize headphone amplifier");
		return ret;
	}

	ret = headphone_amp_enable(true);
	if (ret) {
		LOG_WRN("Failed to enable headphone amplifier: %d", ret);
	}

	/* 3. Initialize battery monitor */
	ret = battery_monitor_init();
	if (ret) {
		LOG_ERR("Failed to initialize battery monitor");
		return ret;
	}

	/* 4. Initialize the music UI layer */
	ret = music_ui_init();
	if (ret) {
		LOG_ERR("Failed to initialize music UI");
		return ret;
	}

	LOG_INF("Music player hardware initialized successfully");
	return 0;
}
